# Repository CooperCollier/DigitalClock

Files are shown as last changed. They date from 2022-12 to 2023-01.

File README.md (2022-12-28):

# DigitalClock
A 12-hour digital clock made out of logic gates and flip-flops and implemented in Logisim.

This project incorporates the logisim 7-segment-display driver created here: https://github.com/marceloboeira/logisim-7-segment-display-driver.



How to open this project:

1: clone this repository with `git clone https://github.com/CooperCollier/DigitalClock --recursive`. The recursive tag is necessary to include the 7-segment-display driver.

2: Open the file clock.circ in logisim.

3: Under the 'simulate' tab, set 'tick frequency' to 2Hz.

4: Under the 'simulate' tab, set 'ticks enabled' to true.

How to use the clock:

Press the SET TIME button to make the clock enter or exit the SET TIME state. When the clock is in the SET TIME state, the SET TIME LED will be turned on. When the clock enters the SET TIME state, the time is immediately reset to 12:00 AM. 

Press the +MIN and +HOUR buttons to change the displayed time. These buttons are only active when the clock is in the SET TIME state.

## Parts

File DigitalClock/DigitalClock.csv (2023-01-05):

Collated Components:
Qty | Part name | Part type | Reference(s) | Value | LibPart | Footprint
1 | ~ |  | C1 | 10nF | Device:C_Small | Capacitor_THT:C_Disc_D5.0mm_W2.5mm_P5.00mm
3 | ~ |  | C2, C3, C4 | 100nF | Device:C_Small | Capacitor_THT:C_Disc_D5.0mm_W2.5mm_P5.00mm
3 | ~ |  | C5, C6, C7 | 10uF | Device:C_Small | Capacitor_THT:CP_Radial_Tantal_D5.0mm_P5.00mm
2 | LTL-4233 | LED | D1, D2 | LED | Device:LED | LED_THT:LED_D3.0mm
1 | ??? | Terminal Block | J1 | Battery | Connector:Conn_01x02_Female | TerminalBlock_Phoenix:TerminalBlock_Phoenix_MKDS-1,5-2_1x02_P5.00mm_Horizontal
3 | 2N3094 | BJT | Q1, Q2, Q3 | 2N3904 | Transistor_BJT:2N3904 | Package_TO_SOT_THT:TO-92_Inline
7 | ~ |  | R1, R2, R3, R4, R5, R6, R12 | 10k | Device:R_Small_US | Resistor_THT:R_Axial_DIN0207_L6.3mm_D2.5mm_P10.16mm_Horizontal
1 | ~ |  | R7 | 4.2k | Device:R_Small_US | Resistor_THT:R_Axial_DIN0207_L6.3mm_D2.5mm_P10.16mm_Horizontal
1 | ~ |  | R8 | 70 | Device:R_Small_US | Resistor_THT:R_Axial_DIN0207_L6.3mm_D2.5mm_P10.16mm_Horizontal
1 | ~ |  | R9 | 70k | Device:R_Small_US | Resistor_THT:R_Axial_DIN0207_L6.3mm_D2.5mm_P10.16mm_Horizontal
33 | ~ |  | R10, R11, R13, R14, R15, R16, R17, R18, R19, R20, R21, R22, R23, R24, R25, R26, R27, R28, R29, R30, R31, R32, R33, R34, R35, R36, R37, R38, R39, R40, R41, R42, R43 | 1k | Device:R_Small_US | Resistor_THT:R_Axial_DIN0207_L6.3mm_D2.5mm_P10.16mm_Horizontal
3 | B3F-1000 | B3F-1000 | SW1, SW2, SW3 | SW_Push | Switch:SW_Push | Button_Switch_THT:SW_PUSH_6mm
4 | SN74LS47N | BCD to 7 segment decoder | U1, U6, U8, U12 | 74LS47 | 74xx:74LS47 | Package_DIP:DIP-16_W7.62mm
1 | NE555P | 555 Timer | U2 | NE555P | Timer:NE555P | Package_DIP:DIP-8_W7.62mm
4 | LSHD-5601 | 7 segment display | U3, U7, U10, U14 | HDSP-7801 | Display_Character:HDSP-7801 | Display_7Segment:7SegmentLED_LTS6760_LTS6780
16 | SN74HC08N | AND gate | U4, U16, U20, U21, U25, U28, U29, U32, U33, U37, U42, U43, U47, U48, U51, U53 | 74LS08 | 74xx:74LS08 | Package_DIP:DIP-14_W7.62mm
4 | SN74HC32N | OR gate | U5, U49, U50, U52 | 74LS32 | 74xx:74LS32 | Package_DIP:DIP-14_W7.62mm
16 | SN74HC74N | Flip Flop | U9, U13, U17, U22, U23, U24, U26, U27, U31, U34, U35, U38, U40, U41, U45, U46 | 74LS74 | 74xx:74LS74 | Package_DIP:DIP-14_W7.62mm
1 | LM1117T-5.0/NOPB | Linear regulator (5V) | U11 | LM1117-5.0 | Regulator_Linear:LM1117-5.0 | Package_TO_SOT_THT:TO-220-3_Vertical
2 | SN74LS14N | Inverter (schmitt triggered) | U15, U54 | 74LS04 | 74xx:74LS04 | Package_DIP:DIP-14_W7.62mm
6 | SN74HC86N | XOR gate | U18, U19, U30, U36, U39, U44 | 74LS86 | 74xx:74LS86 | Package_DIP:DIP-14_W7.62mm

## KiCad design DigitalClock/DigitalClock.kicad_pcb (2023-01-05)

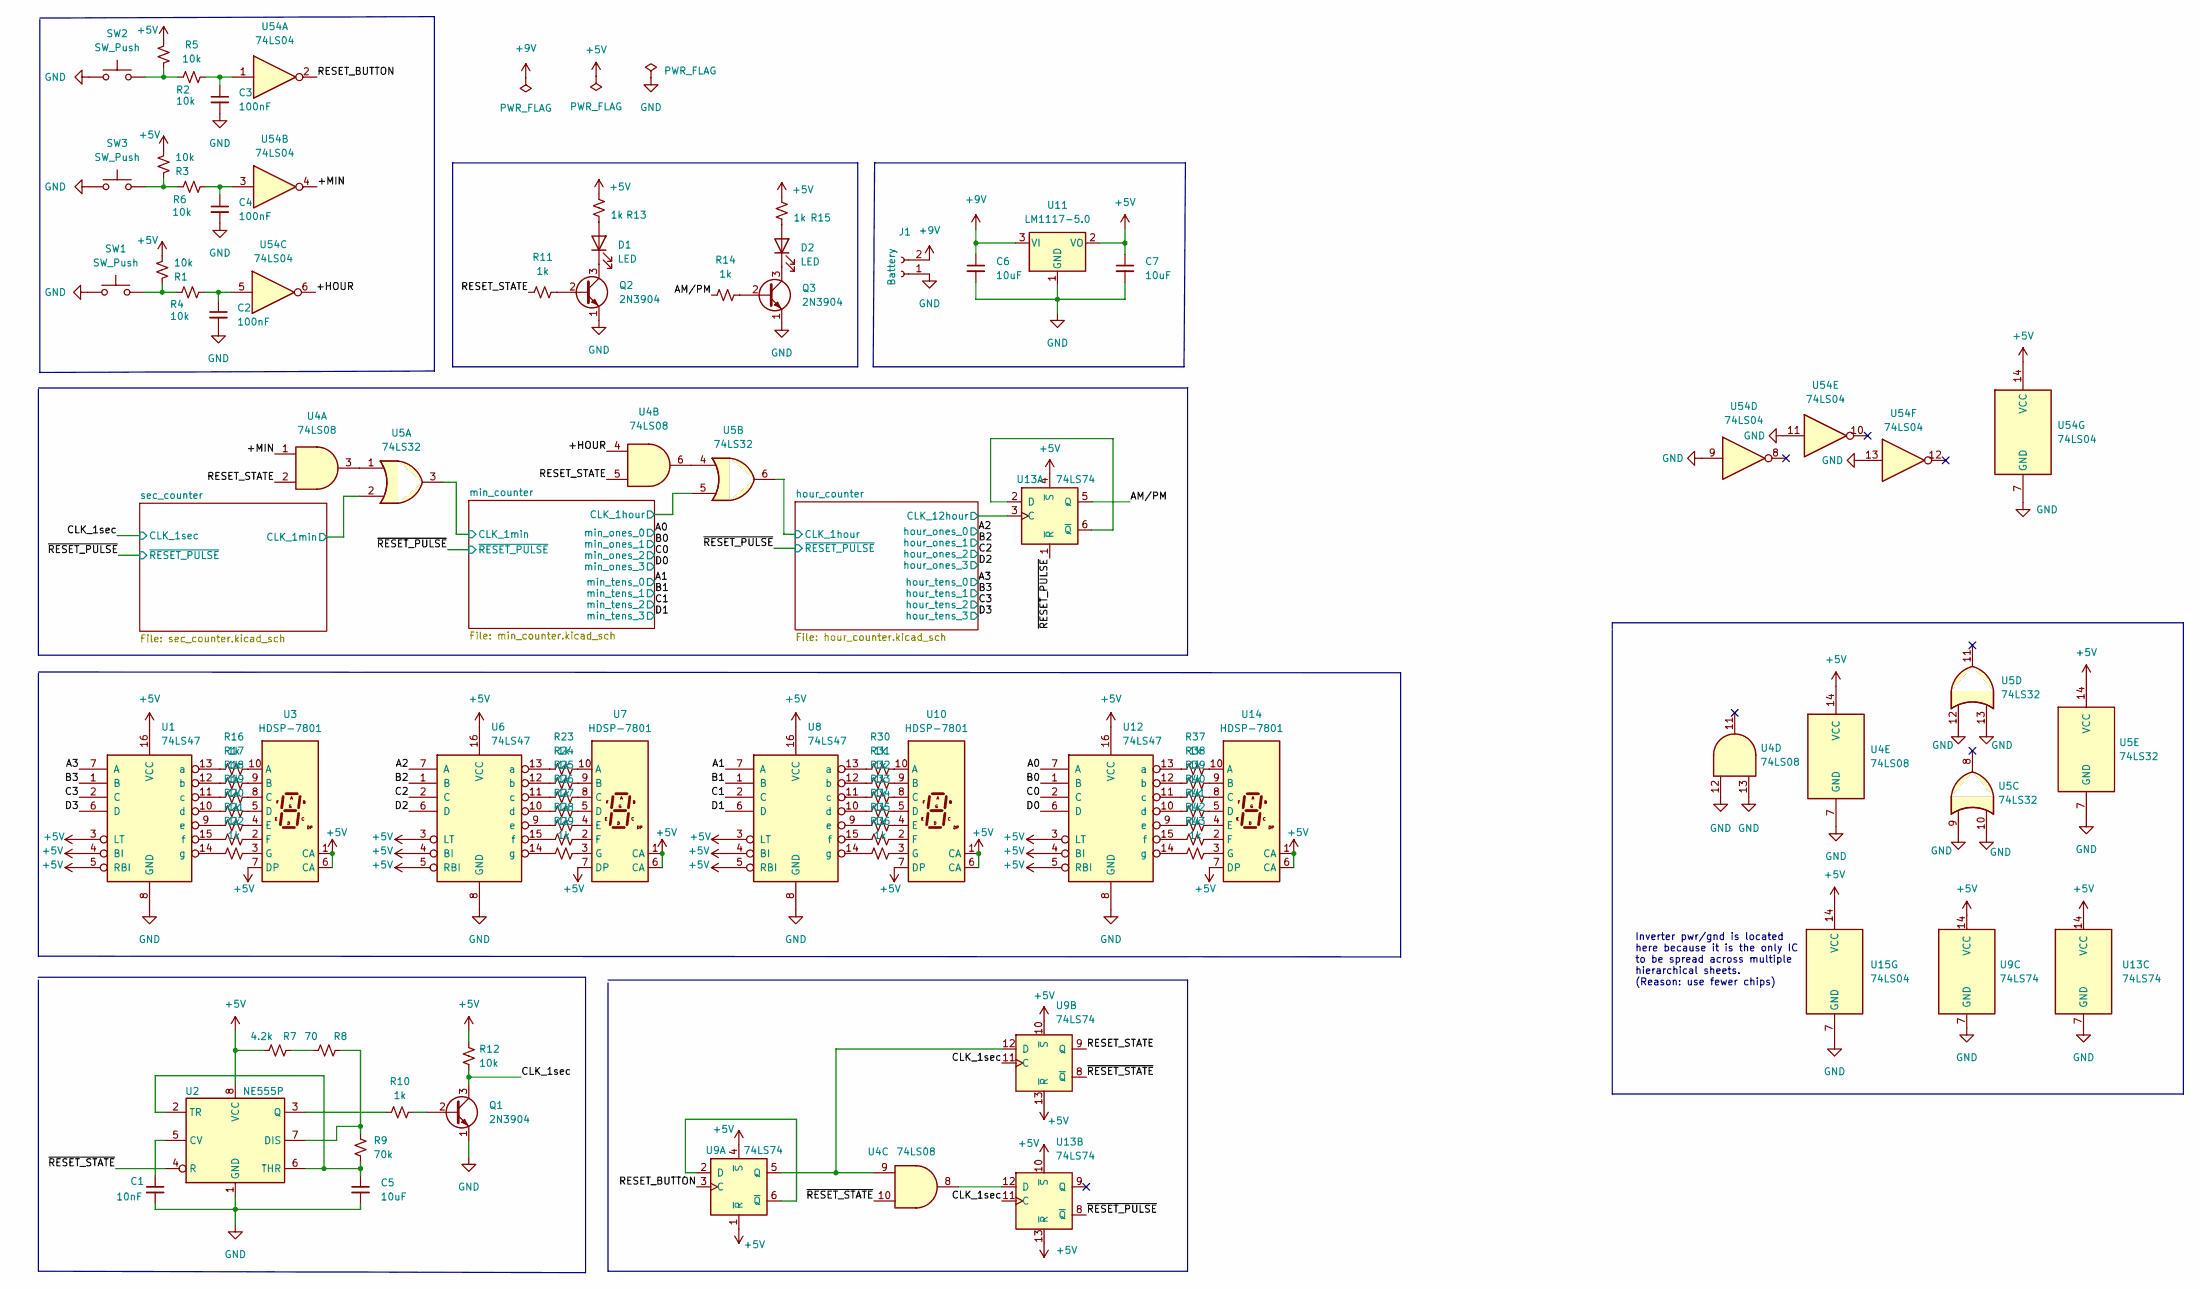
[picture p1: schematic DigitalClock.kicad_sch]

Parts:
C1: 10nF; C_Disc_D5.0mm_W2.5mm_P5.00mm
C2, C3, C4: 100nF; C_Disc_D5.0mm_W2.5mm_P5.00mm
C5, C6, C7: 10uF; CP_Radial_Tantal_D5.0mm_P5.00mm
D1, D2: LED; LED_D3.0mm
J1: Battery; TerminalBlock_Phoenix_MKDS-1,5-2_1x02_P5.00mm_Horizontal
Q1, Q2, Q3: 2N3904; TO-92_Inline
R1, R2, R3, R4, R5, R6, R12: 10k; R_Axial_DIN0207_L6.3mm_D2.5mm_P10.16mm_Horizontal
R7: 4.2k; R_Axial_DIN0207_L6.3mm_D2.5mm_P10.16mm_Horizontal
R8: 70; R_Axial_DIN0207_L6.3mm_D2.5mm_P10.16mm_Horizontal
R9: 70k; R_Axial_DIN0207_L6.3mm_D2.5mm_P10.16mm_Horizontal
R10, R11, R13, R14, R15, R16, R17, R18, R19, R20, R21, R22, R23, R24, R25, R26, R27, R28, R29, R30, R31, R32, R33, R34, R35, R36, R37, R38, R39, R40, R41, R42, R43: 1k; R_Axial_DIN0207_L6.3mm_D2.5mm_P10.16mm_Horizontal
SW1, SW2, SW3: SW_Push; SW_PUSH_6mm
U1, U6, U8, U12: 74LS47; DIP-16_W7.62mm
U2: NE555P; DIP-8_W7.62mm
U3, U7, U10, U14: HDSP-7801; 7SegmentLED_LTS6760_LTS6780
U4: 74LS08; DIP-14_W7.62mm
U5: 74LS32; DIP-14_W7.62mm
U9, U13: 74LS74; DIP-14_W7.62mm
U11: LM1117-5.0; TO-220-3_Vertical
U15, U54: 74LS04; DIP-14_W7.62mm

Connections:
+5V: C7.1, R1.2, R2.2, R3.2, R7.1, R12.2, R13.2, R15.2, U1.3 (LT), U1.4 (BI), U1.5 (RBI), U1.16 (VCC), U2.8 (VCC), U3.1 (CA), U3.6 (CA), U3.7 (DP), U4.14 (VCC), U5.14 (VCC), U6.3 (LT), U6.4 (BI), U6.5 (RBI), U6.16 (VCC), U7.1 (CA), U7.6 (CA), U7.7 (DP), U8.3 (LT), U8.4 (BI), U8.5 (RBI), U8.16 (VCC), U9.1 (~R), U9.4 (~S), U9.10 (~S), U9.13 (~R), U9.14 (VCC), U10.1 (CA), U10.6 (CA), U10.7 (DP), U11.2 (VO), U12.3 (LT), U12.4 (BI), U12.5 (RBI), U12.16 (VCC), U13.4 (~S), U13.10 (~S), U13.13 (~R), U13.14 (VCC), U14.1 (CA), U14.6 (CA), U14.7 (DP), U15.14 (VCC), U54.14 (VCC); also elsewhere on the board
+9V: C6.1, J1.2, U11.3 (VI)
/+HOUR: U4.4, U54.6
/+MIN: U4.1, U54.4
/A0: U12.7 (A); also elsewhere on the board
/A1: U8.7 (A); also elsewhere on the board
/A2: U6.7 (A); also elsewhere on the board
/A3: U1.7 (A); also elsewhere on the board
/AM/PM: R14.1, U13.5 (Q)
/B0: U12.1 (B); also elsewhere on the board
/B1: U8.1 (B); also elsewhere on the board
/B2: U6.1 (B); also elsewhere on the board
/B3: U1.1 (B); also elsewhere on the board
/C0: U12.2 (C); also elsewhere on the board
/C1: U8.2 (C); also elsewhere on the board
/C2: U6.2 (C); also elsewhere on the board
/C3: U1.2 (C); also elsewhere on the board
/CLK_1sec: Q1.3 (C), R12.1, U9.11 (C), U13.11 (C); also elsewhere on the board
/D0: U12.6 (D); also elsewhere on the board
/D1: U8.6 (D); also elsewhere on the board
/D2: U6.6 (D); also elsewhere on the board
/D3: U1.6 (D); also elsewhere on the board
/RESET_BUTTON: U9.3 (C), U54.2
/RESET_STATE: R11.1, U4.2, U4.5, U9.9 (Q)
/hour_counter/CLK_1hour: U5.6; also elsewhere on the board
/hour_counter/CLK_12hour: U13.3 (C); also elsewhere on the board
/min_counter/CLK_1hour: U5.5; also elsewhere on the board
/min_counter/CLK_1min: U5.3; also elsewhere on the board
/sec_counter/CLK_1min: U5.2; also elsewhere on the board
/~RESET_PULSE: U13.1 (~R), U13.8 (~Q); also elsewhere on the board
/~RESET_STATE: U2.4 (R), U4.10, U9.8 (~Q)
GND: C1.2, C2.2, C3.2, C4.2, C5.2, C6.2, C7.2, J1.1, Q1.1 (E), Q2.1 (E), Q3.1 (E), SW1.1, SW2.1, SW3.1, U1.8 (GND), U2.1 (GND), U4.7 (GND), U4.12, U4.13, U5.7 (GND), U5.9, U5.10, U5.12, U5.13, U6.8 (GND), U8.8 (GND), U9.7 (GND), U11.1 (GND), U12.8 (GND), U13.7 (GND), U15.7 (GND), U54.7 (GND), U54.9, U54.11, U54.13; also elsewhere on the board
unnamed: C1.1, U2.5 (CV)
unnamed: C2.1, R4.2, U54.5
unnamed: C3.1, R5.2, U54.1
unnamed: C4.1, R6.2, U54.3
unnamed: C5.1, R9.2, U2.2 (TR), U2.6 (THR)
unnamed: D1.1 (K), Q2.3 (C)
unnamed: D1.2 (A), R13.1
unnamed: D2.1 (K), Q3.3 (C)
unnamed: D2.2 (A), R15.1
unnamed: Q1.2 (B), R10.2
unnamed: Q2.2 (B), R11.2
unnamed: Q3.2 (B), R14.2
unnamed: R1.1, R4.1, SW1.2
unnamed: R2.1, R5.1, SW2.2
unnamed: R3.1, R6.1, SW3.2
unnamed: R7.2, R8.1
unnamed: R8.2, R9.1, U2.7 (DIS)
unnamed: R10.1, U2.3 (Q)
unnamed: R16.1, U1.13 (a)
unnamed: R16.2, U3.10 (A)
unnamed: R17.1, U1.12 (b)
unnamed: R17.2, U3.9 (B)
unnamed: R18.1, U1.11 (c)
unnamed: R18.2, U3.8 (C)
unnamed: R19.1, U1.10 (d)
unnamed: R19.2, U3.5 (D)
unnamed: R20.1, U1.9 (e)
unnamed: R20.2, U3.4 (E)
unnamed: R21.1, U1.15 (f)
unnamed: R21.2, U3.2 (F)
unnamed: R22.1, U1.14 (g)
unnamed: R22.2, U3.3 (G)
unnamed: R23.1, U6.13 (a)
unnamed: R23.2, U7.10 (A)
unnamed: R24.1, U6.12 (b)
unnamed: R24.2, U7.9 (B)
unnamed: R25.1, U6.11 (c)
unnamed: R25.2, U7.8 (C)
unnamed: R26.1, U6.10 (d)
unnamed: R26.2, U7.5 (D)
unnamed: R27.1, U6.9 (e)
unnamed: R27.2, U7.4 (E)
unnamed: R28.1, U6.15 (f)
unnamed: R28.2, U7.2 (F)
unnamed: R29.1, U6.14 (g)
unnamed: R29.2, U7.3 (G)
unnamed: R30.1, U8.13 (a)
unnamed: R30.2, U10.10 (A)
unnamed: R31.1, U8.12 (b)
unnamed: R31.2, U10.9 (B)
unnamed: R32.1, U8.11 (c)
unnamed: R32.2, U10.8 (C)
unnamed: R33.1, U8.10 (d)
unnamed: R33.2, U10.5 (D)
unnamed: R34.1, U8.9 (e)
unnamed: R34.2, U10.4 (E)
unnamed: R35.1, U8.15 (f)
unnamed: R35.2, U10.2 (F)
unnamed: R36.1, U8.14 (g)
unnamed: R36.2, U10.3 (G)
unnamed: R37.1, U12.13 (a)
unnamed: R37.2, U14.10 (A)
unnamed: R38.1, U12.12 (b)
unnamed: R38.2, U14.9 (B)
unnamed: R39.1, U12.11 (c)
unnamed: R39.2, U14.8 (C)
unnamed: R40.1, U12.10 (d)
unnamed: R40.2, U14.5 (D)
unnamed: R41.1, U12.9 (e)
unnamed: R41.2, U14.4 (E)
unnamed: R42.1, U12.15 (f)
unnamed: R42.2, U14.2 (F)
unnamed: R43.1, U12.14 (g)
unnamed: R43.2, U14.3 (G)
unnamed: U4.3, U5.1
unnamed: U4.6, U5.4
unnamed: U4.9, U9.5 (Q), U9.12 (D)
unnamed: U9.2 (D), U9.6 (~Q)
unnamed: U13.2 (D), U13.6 (~Q)
unnamed: U4.8, U13.12 (D)

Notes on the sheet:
Inverter pwr/gnd is located here because it is the only IC to be spread across multiple hierarchical sheets. (Reason: use fewer chips)

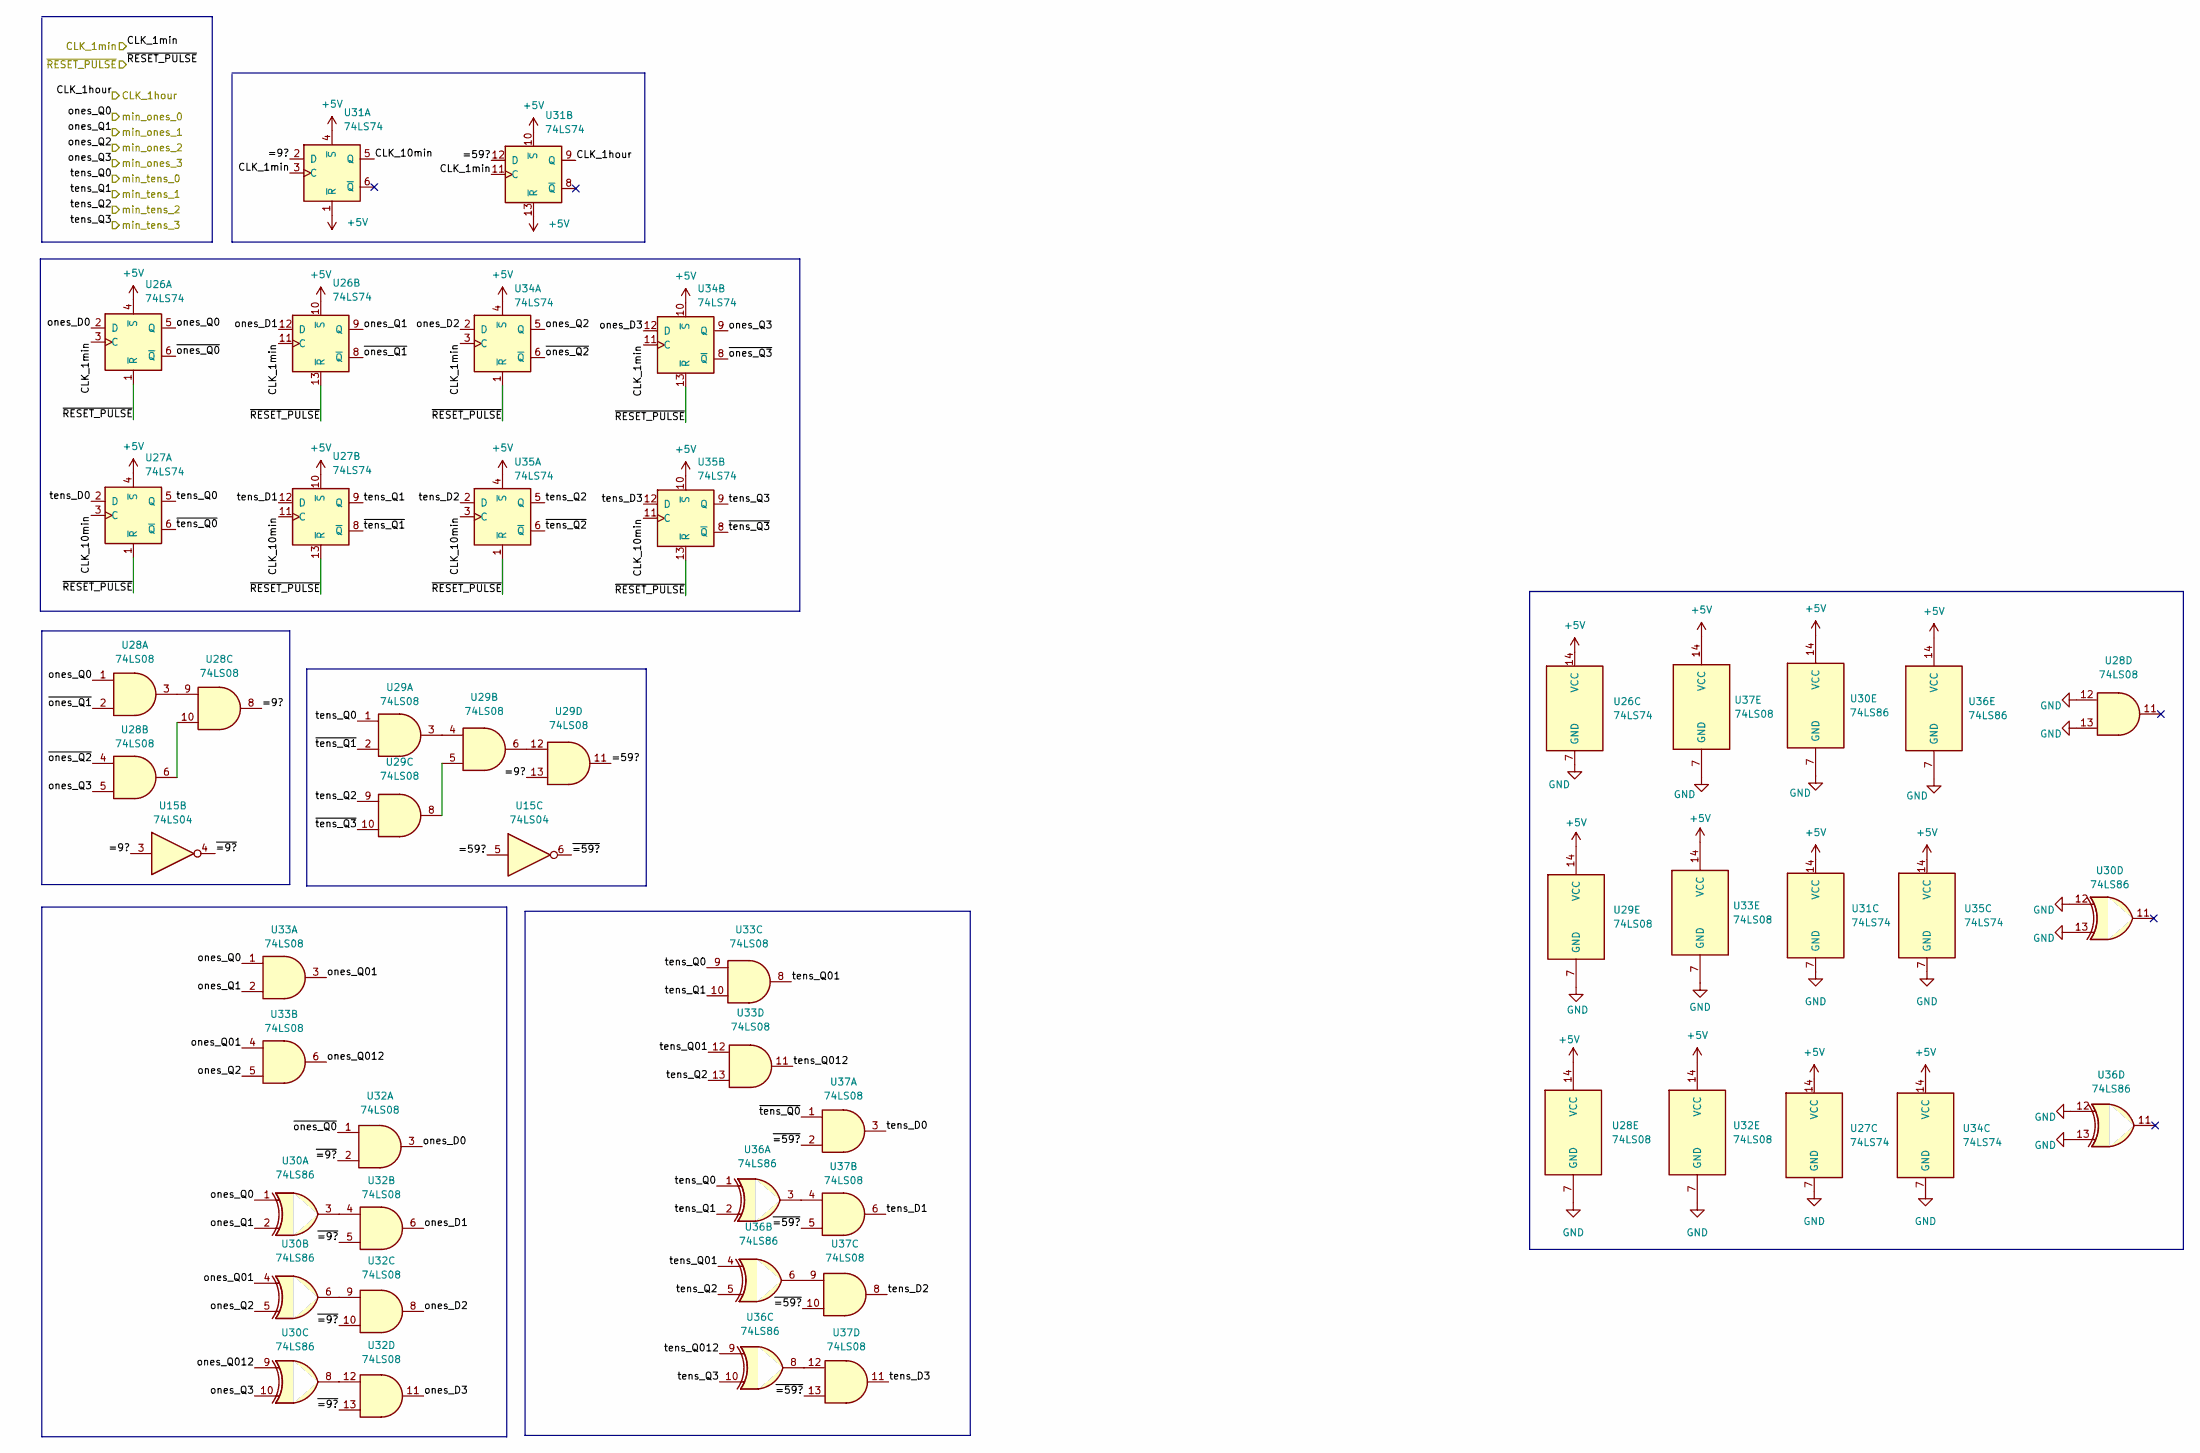
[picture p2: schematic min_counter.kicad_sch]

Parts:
U15: 74LS04; DIP-14_W7.62mm
U26, U27, U31, U34, U35: 74LS74; DIP-14_W7.62mm
U28, U29, U32, U33, U37: 74LS08; DIP-14_W7.62mm
U30, U36: 74LS86; DIP-14_W7.62mm

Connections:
+5V: U26.4 (~S), U26.10 (~S), U26.14 (VCC), U27.4 (~S), U27.10 (~S), U27.14 (VCC), U28.14 (VCC), U29.14 (VCC), U30.14 (VCC), U31.1 (~R), U31.4 (~S), U31.10 (~S), U31.13 (~R), U31.14 (VCC), U32.14 (VCC), U33.14 (VCC), U34.4 (~S), U34.10 (~S), U34.14 (VCC), U35.4 (~S), U35.10 (~S), U35.14 (VCC), U36.14 (VCC), U37.14 (VCC); also elsewhere on the board
/A0: U26.5 (Q), U28.1, U30.1, U33.1; also elsewhere on the board
/A1: U27.5 (Q), U29.1, U33.9, U36.1; also elsewhere on the board
/B0: U26.9 (Q), U30.2, U33.2; also elsewhere on the board
/B1: U27.9 (Q), U33.10, U36.2; also elsewhere on the board
/C0: U30.5, U33.5, U34.5 (Q); also elsewhere on the board
/C1: U29.9, U33.13, U35.5 (Q), U36.5; also elsewhere on the board
/D0: U28.5, U30.10, U34.9 (Q); also elsewhere on the board
/D1: U35.9 (Q), U36.10; also elsewhere on the board
/min_counter/=9?: U15.3, U28.8, U29.13, U31.2 (D)
/min_counter/=59?: U15.5, U29.11, U31.12 (D)
/min_counter/CLK_1hour: U31.9 (Q); also elsewhere on the board
/min_counter/CLK_1min: U26.3 (C), U26.11 (C), U31.3 (C), U31.11 (C), U34.3 (C), U34.11 (C); also elsewhere on the board
/min_counter/CLK_10min: U27.3 (C), U27.11 (C), U31.5 (Q), U35.3 (C), U35.11 (C)
/min_counter/ones_D0: U26.2 (D), U32.3
/min_counter/ones_D1: U26.12 (D), U32.6
/min_counter/ones_D2: U32.8, U34.2 (D)
/min_counter/ones_D3: U32.11, U34.12 (D)
/min_counter/ones_Q01: U30.4, U33.3, U33.4
/min_counter/ones_Q012: U30.9, U33.6
/min_counter/tens_D0: U27.2 (D), U37.3
/min_counter/tens_D1: U27.12 (D), U37.6
/min_counter/tens_D2: U35.2 (D), U37.8
/min_counter/tens_D3: U35.12 (D), U37.11
/min_counter/tens_Q01: U33.8, U33.12, U36.4
/min_counter/tens_Q012: U33.11, U36.9
/min_counter/~=9?: U15.4, U32.2, U32.5, U32.10, U32.13
/min_counter/~=59?: U15.6, U37.2, U37.5, U37.10, U37.13
/min_counter/~ones_Q0: U26.6 (~Q), U32.1
/min_counter/~ones_Q1: U26.8 (~Q), U28.2
/min_counter/~ones_Q2: U28.4, U34.6 (~Q)
/min_counter/~ones_Q3: U34.8 (~Q)
/min_counter/~tens_Q0: U27.6 (~Q), U37.1
/min_counter/~tens_Q1: U27.8 (~Q), U29.2
/min_counter/~tens_Q2: U35.6 (~Q)
/min_counter/~tens_Q3: U29.10, U35.8 (~Q)
/~RESET_PULSE: U26.1 (~R), U26.13 (~R), U27.1 (~R), U27.13 (~R), U34.1 (~R), U34.13 (~R), U35.1 (~R), U35.13 (~R); also elsewhere on the board
GND: U26.7 (GND), U27.7 (GND), U28.7 (GND), U28.12, U28.13, U29.7 (GND), U30.7 (GND), U30.12, U30.13, U31.7 (GND), U32.7 (GND), U33.7 (GND), U34.7 (GND), U35.7 (GND), U36.7 (GND), U36.12, U36.13, U37.7 (GND); also elsewhere on the board
unnamed: U28.3, U28.9
unnamed: U28.6, U28.10
unnamed: U29.3, U29.4
unnamed: U29.5, U29.8
unnamed: U29.6, U29.12
unnamed: U30.3, U32.4
unnamed: U30.6, U32.9
unnamed: U30.8, U32.12
unnamed: U36.3, U37.4
unnamed: U36.6, U37.9
unnamed: U36.8, U37.12

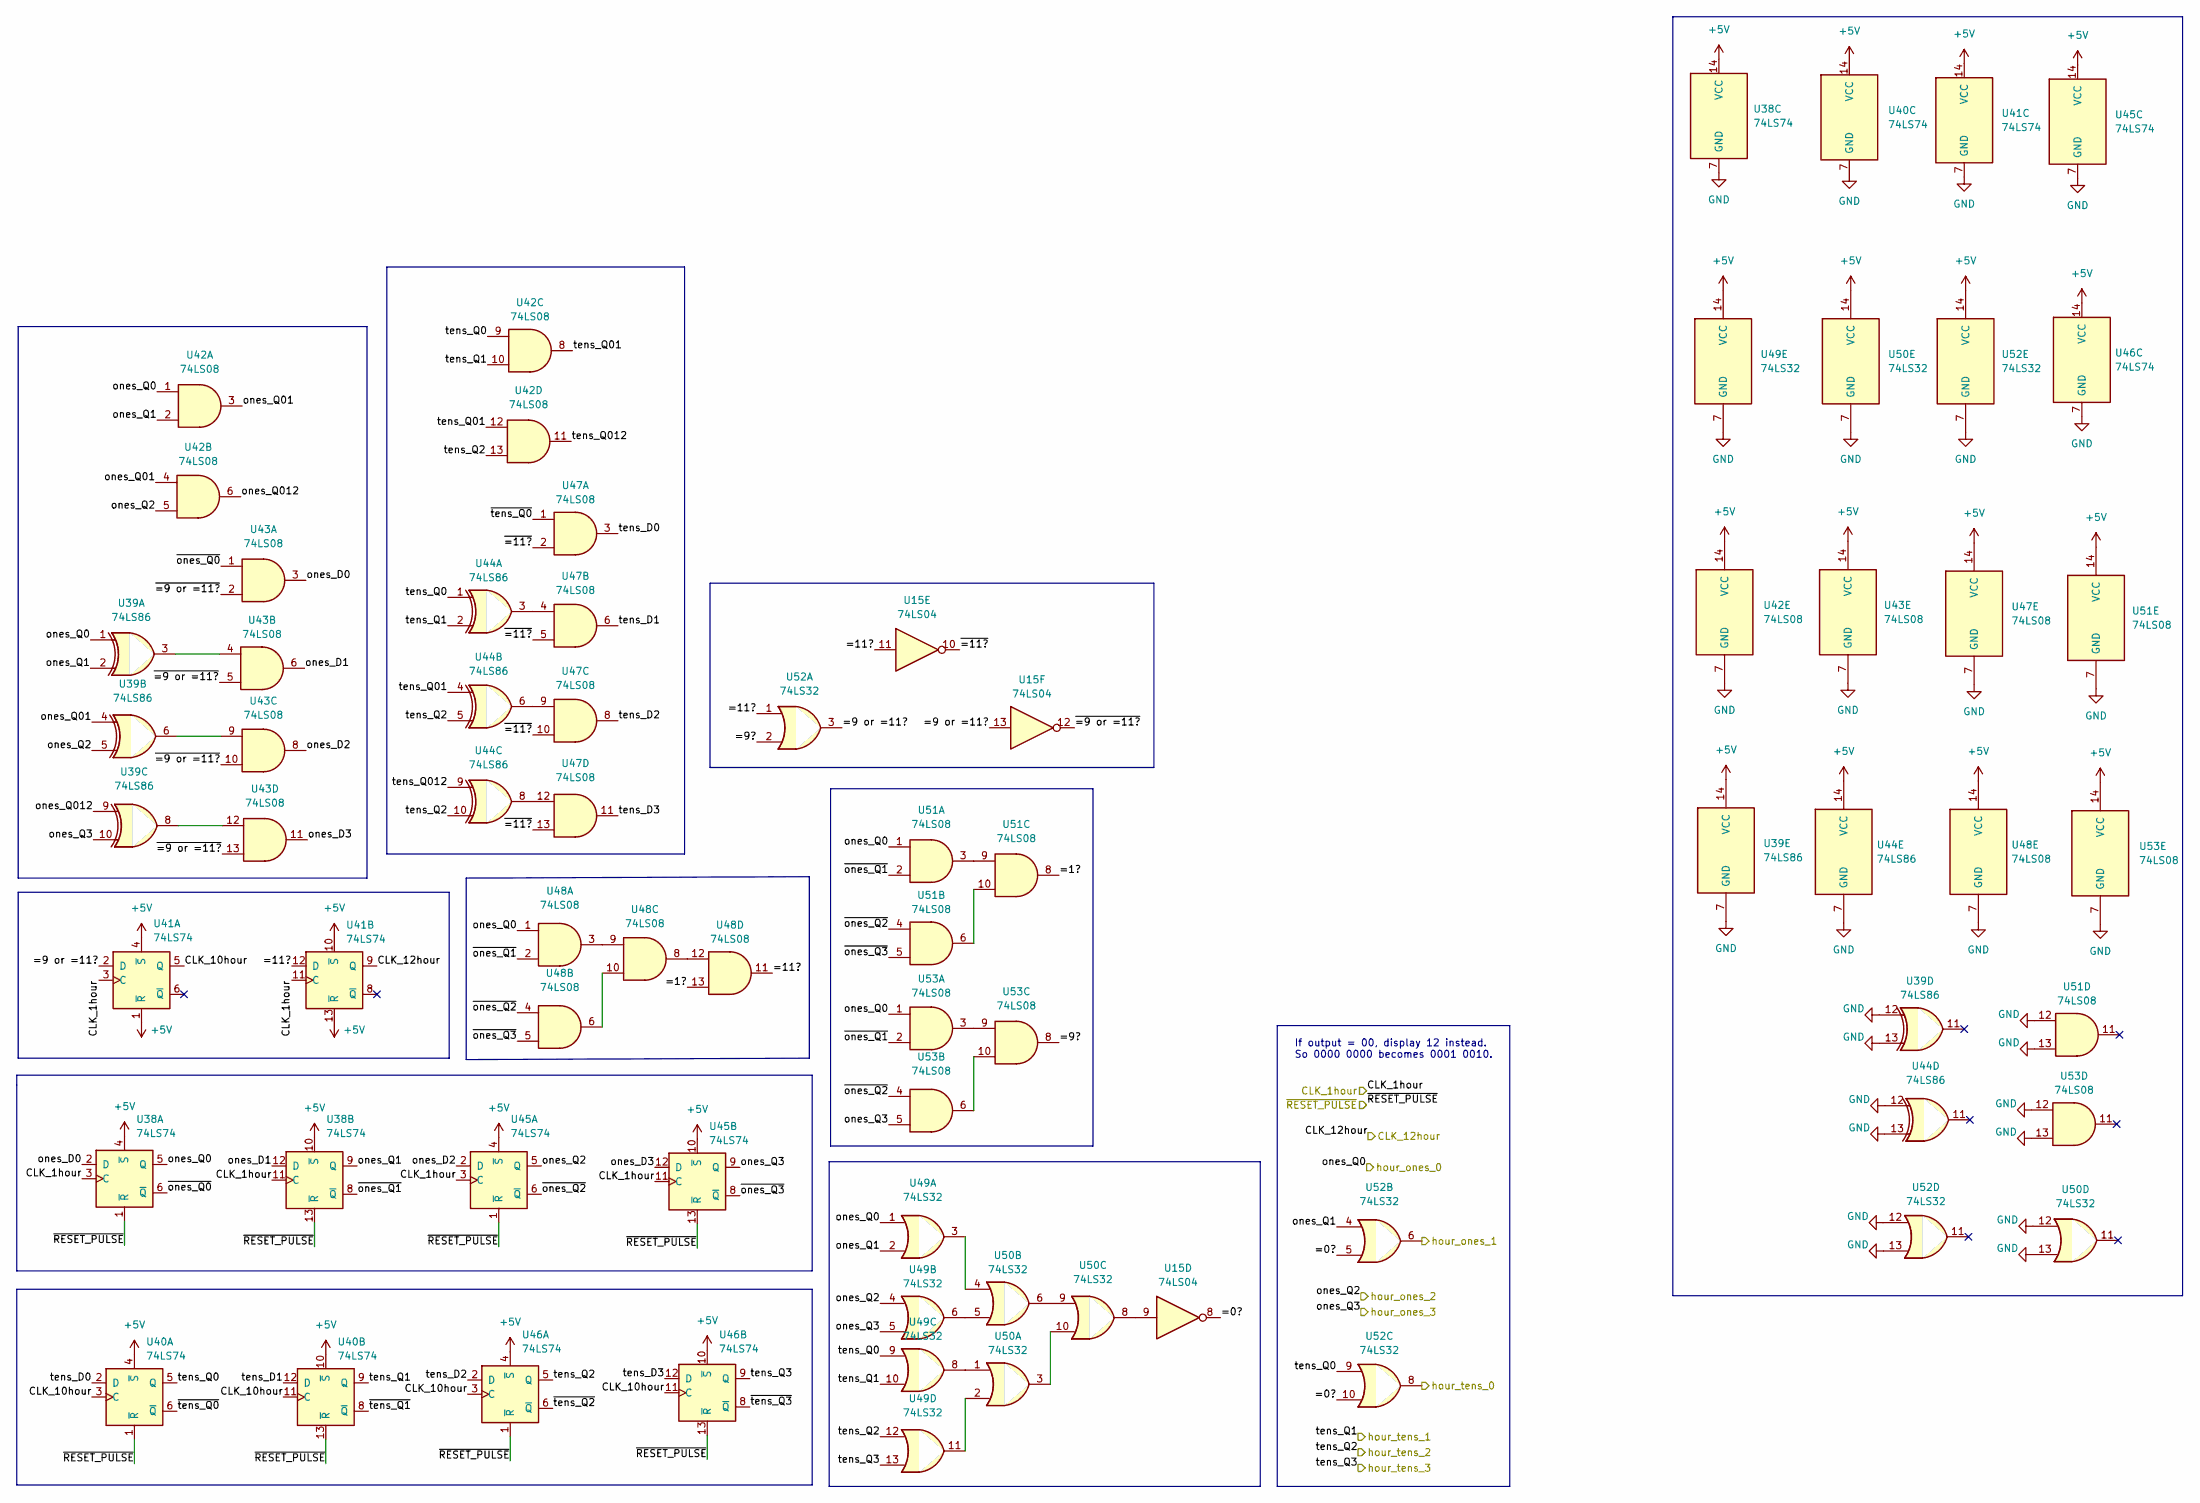
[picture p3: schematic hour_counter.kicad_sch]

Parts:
U15: 74LS04; DIP-14_W7.62mm
U38, U40, U41, U45, U46: 74LS74; DIP-14_W7.62mm
U39, U44: 74LS86; DIP-14_W7.62mm
U42, U43, U47, U48, U51, U53: 74LS08; DIP-14_W7.62mm
U49, U50, U52: 74LS32; DIP-14_W7.62mm

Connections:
+5V: U38.4 (~S), U38.10 (~S), U38.14 (VCC), U39.14 (VCC), U40.4 (~S), U40.10 (~S), U40.14 (VCC), U41.1 (~R), U41.4 (~S), U41.10 (~S), U41.13 (~R), U41.14 (VCC), U42.14 (VCC), U43.14 (VCC), U44.14 (VCC), U45.4 (~S), U45.10 (~S), U45.14 (VCC), U46.4 (~S), U46.10 (~S), U46.14 (VCC), U47.14 (VCC), U48.14 (VCC), U49.14 (VCC), U50.14 (VCC), U51.14 (VCC), U52.14 (VCC), U53.14 (VCC); also elsewhere on the board
/A2: U38.5 (Q), U39.1, U42.1, U48.1, U49.1, U51.1, U53.1; also elsewhere on the board
/A3: U52.8; also elsewhere on the board
/B2: U52.6; also elsewhere on the board
/B3: U40.9 (Q), U42.10, U44.2, U49.10; also elsewhere on the board
/C2: U39.5, U42.5, U45.5 (Q), U49.4; also elsewhere on the board
/C3: U42.13, U44.5, U44.10, U46.5 (Q), U49.12; also elsewhere on the board
/D2: U39.10, U45.9 (Q), U49.5, U53.5; also elsewhere on the board
/D3: U46.9 (Q), U49.13; also elsewhere on the board
/hour_counter/=0?: U15.8, U52.5, U52.10
/hour_counter/=1?: U48.13, U51.8
/hour_counter/=9 or =11?: U15.13, U41.2 (D), U52.3
/hour_counter/=9?: U52.2, U53.8
/hour_counter/=11?: U15.11, U41.12 (D), U48.11, U52.1
/hour_counter/CLK_1hour: U38.3 (C), U38.11 (C), U41.3 (C), U41.11 (C), U45.3 (C), U45.11 (C); also elsewhere on the board
/hour_counter/CLK_10hour: U40.3 (C), U40.11 (C), U41.5 (Q), U46.3 (C), U46.11 (C)
/hour_counter/CLK_12hour: U41.9 (Q); also elsewhere on the board
/hour_counter/ones_D0: U38.2 (D), U43.3
/hour_counter/ones_D1: U38.12 (D), U43.6
/hour_counter/ones_D2: U43.8, U45.2 (D)
/hour_counter/ones_D3: U43.11, U45.12 (D)
/hour_counter/ones_Q1: U38.9 (Q), U39.2, U42.2, U49.2, U52.4
/hour_counter/ones_Q01: U39.4, U42.3, U42.4
/hour_counter/ones_Q012: U39.9, U42.6
/hour_counter/tens_D0: U40.2 (D), U47.3
/hour_counter/tens_D1: U40.12 (D), U47.6
/hour_counter/tens_D2: U46.2 (D), U47.8
/hour_counter/tens_D3: U46.12 (D), U47.11
/hour_counter/tens_Q0: U40.5 (Q), U42.9, U44.1, U49.9, U52.9
/hour_counter/tens_Q01: U42.8, U42.12, U44.4
/hour_counter/tens_Q012: U42.11, U44.9
/hour_counter/~=9 or =11?: U15.12, U43.2, U43.5, U43.10, U43.13
/hour_counter/~=11?: U15.10, U47.2, U47.5, U47.10, U47.13
/hour_counter/~ones_Q0: U38.6 (~Q), U43.1
/hour_counter/~ones_Q1: U38.8 (~Q), U48.2, U51.2, U53.2
/hour_counter/~ones_Q2: U45.6 (~Q), U48.4, U51.4, U53.4
/hour_counter/~ones_Q3: U45.8 (~Q), U48.5, U51.5
/hour_counter/~tens_Q0: U40.6 (~Q), U47.1
/hour_counter/~tens_Q1: U40.8 (~Q)
/hour_counter/~tens_Q2: U46.6 (~Q)
/hour_counter/~tens_Q3: U46.8 (~Q)
/~RESET_PULSE: U38.1 (~R), U38.13 (~R), U40.1 (~R), U40.13 (~R), U45.1 (~R), U45.13 (~R), U46.1 (~R), U46.13 (~R); also elsewhere on the board
GND: U38.7 (GND), U39.7 (GND), U39.12, U39.13, U40.7 (GND), U41.7 (GND), U42.7 (GND), U43.7 (GND), U44.7 (GND), U44.12, U44.13, U45.7 (GND), U46.7 (GND), U47.7 (GND), U48.7 (GND), U49.7 (GND), U50.7 (GND), U50.12, U50.13, U51.7 (GND), U51.12, U51.13, U52.7 (GND), U52.12, U52.13, U53.7 (GND), U53.12, U53.13; also elsewhere on the board
unnamed: U15.9, U50.8
unnamed: U39.3, U43.4
unnamed: U39.6, U43.9
unnamed: U39.8, U43.12
unnamed: U44.3, U47.4
unnamed: U44.6, U47.9
unnamed: U44.8, U47.12
unnamed: U48.3, U48.9
unnamed: U48.6, U48.10
unnamed: U48.8, U48.12
unnamed: U49.3, U50.4
unnamed: U49.6, U50.5
unnamed: U49.8, U50.1
unnamed: U49.11, U50.2
unnamed: U50.6, U50.9
unnamed: U50.3, U50.10
unnamed: U51.3, U51.9
unnamed: U51.6, U51.10
unnamed: U53.3, U53.9
unnamed: U53.6, U53.10

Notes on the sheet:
If output = 00, display 12 instead. So 0000 0000 becomes 0001 0010.

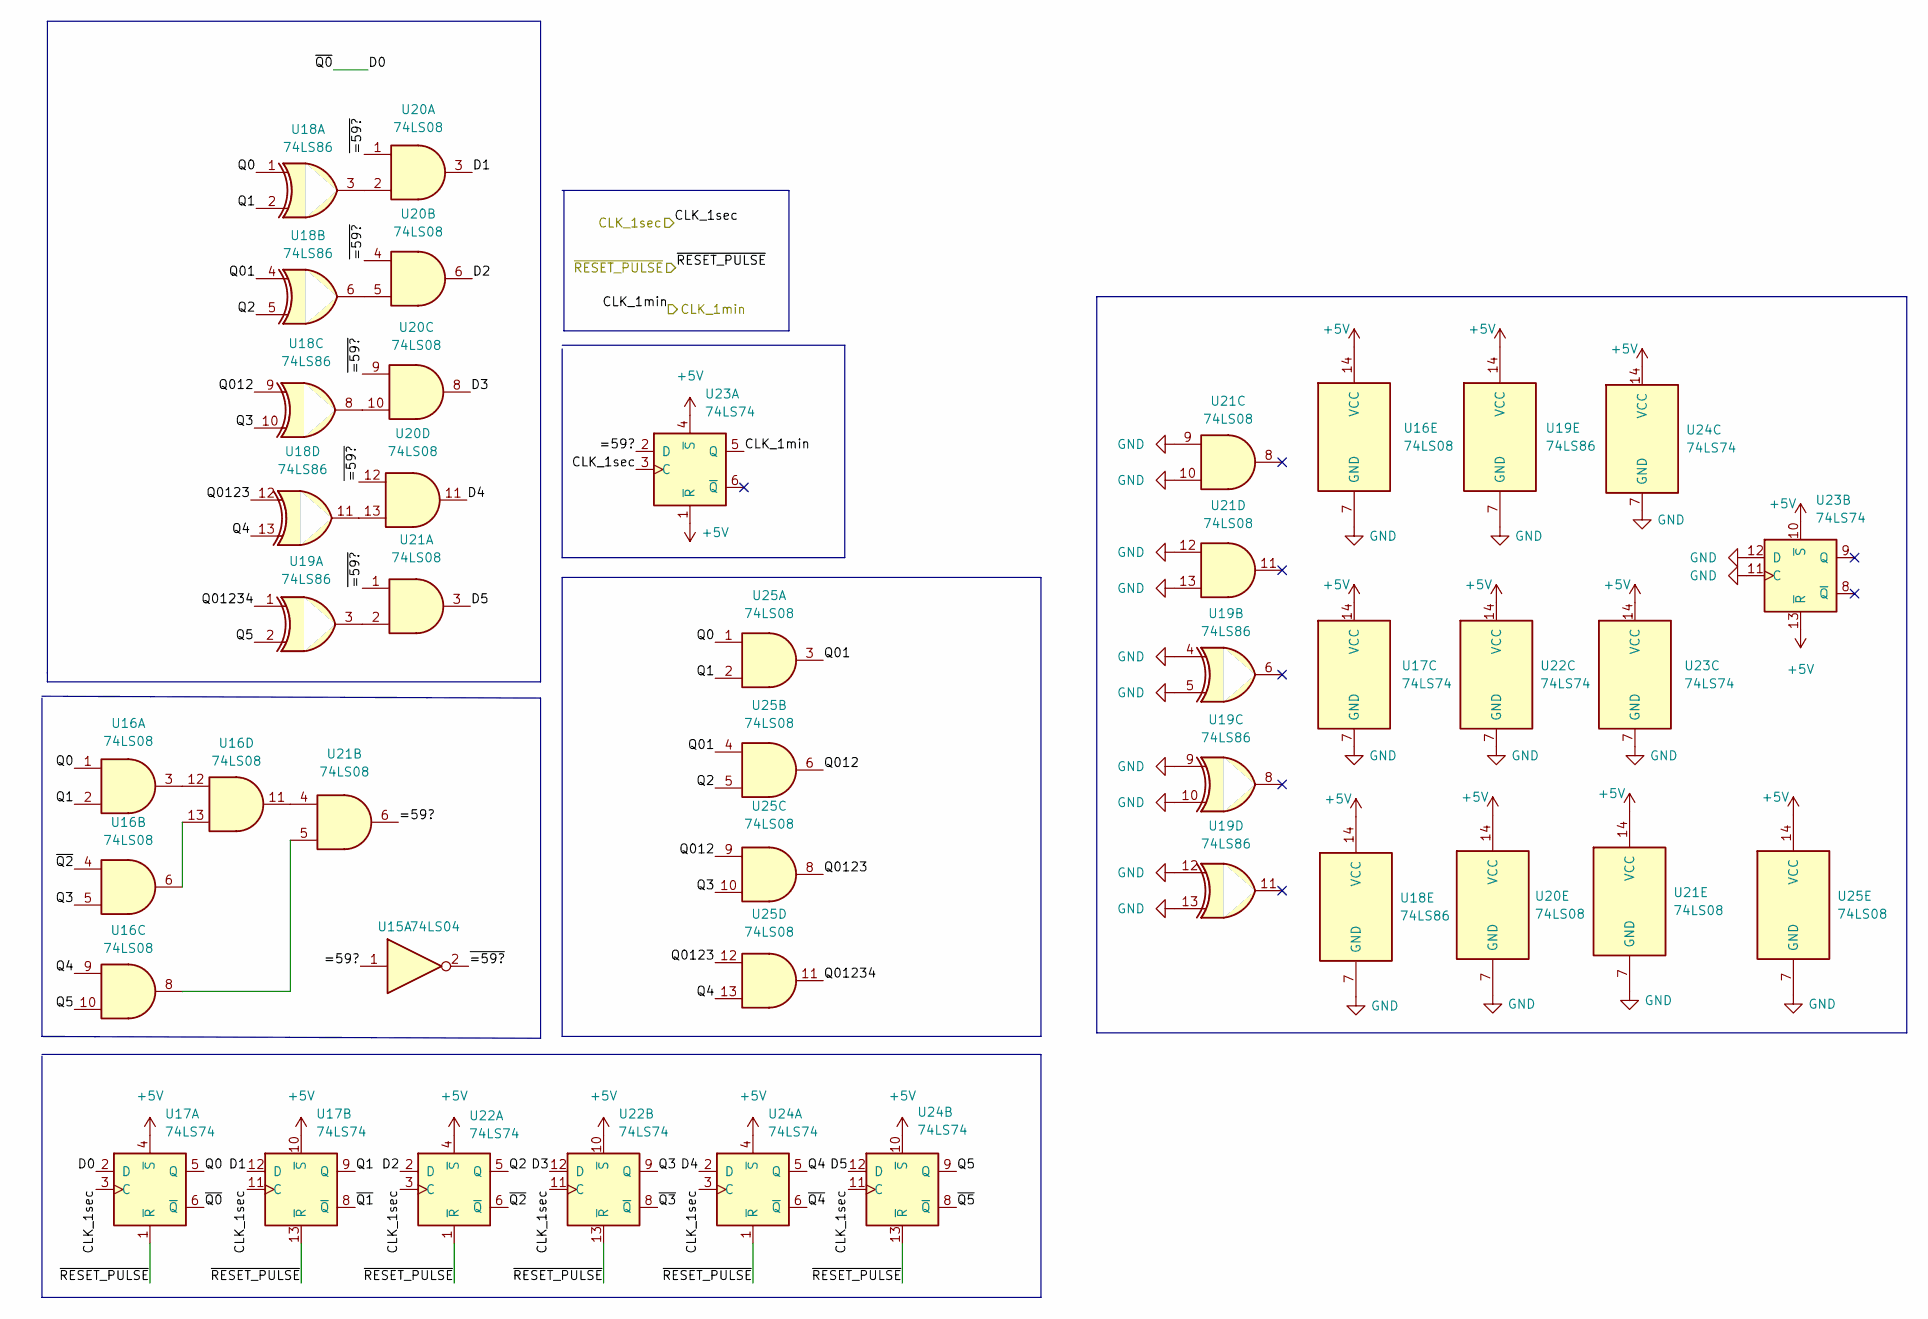
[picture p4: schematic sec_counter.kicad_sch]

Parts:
U15: 74LS04; DIP-14_W7.62mm
U16, U20, U21, U25: 74LS08; DIP-14_W7.62mm
U17, U22, U23, U24: 74LS74; DIP-14_W7.62mm
U18, U19: 74LS86; DIP-14_W7.62mm

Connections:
+5V: U16.14 (VCC), U17.4 (~S), U17.10 (~S), U17.14 (VCC), U18.14 (VCC), U19.14 (VCC), U20.14 (VCC), U21.14 (VCC), U22.4 (~S), U22.10 (~S), U22.14 (VCC), U23.1 (~R), U23.4 (~S), U23.10 (~S), U23.13 (~R), U23.14 (VCC), U24.4 (~S), U24.10 (~S), U24.14 (VCC), U25.14 (VCC); also elsewhere on the board
/CLK_1sec: U17.3 (C), U17.11 (C), U22.3 (C), U22.11 (C), U23.3 (C), U24.3 (C), U24.11 (C); also elsewhere on the board
/sec_counter/=59?: U15.1, U21.6, U23.2 (D)
/sec_counter/CLK_1min: U23.5 (Q); also elsewhere on the board
/sec_counter/D0: U17.2 (D), U17.6 (~Q)
/sec_counter/D1: U17.12 (D), U20.3
/sec_counter/D2: U20.6, U22.2 (D)
/sec_counter/D3: U20.8, U22.12 (D)
/sec_counter/D4: U20.11, U24.2 (D)
/sec_counter/D5: U21.3, U24.12 (D)
/sec_counter/Q0: U16.1, U17.5 (Q), U18.1, U25.1
/sec_counter/Q1: U16.2, U17.9 (Q), U18.2, U25.2
/sec_counter/Q01: U18.4, U25.3, U25.4
/sec_counter/Q2: U18.5, U22.5 (Q), U25.5
/sec_counter/Q3: U16.5, U18.10, U22.9 (Q), U25.10
/sec_counter/Q4: U16.9, U18.13, U24.5 (Q), U25.13
/sec_counter/Q5: U16.10, U19.2, U24.9 (Q)
/sec_counter/Q012: U18.9, U25.6, U25.9
/sec_counter/Q0123: U18.12, U25.8, U25.12
/sec_counter/Q01234: U19.1, U25.11
/sec_counter/~=59?: U15.2, U20.1, U20.4, U20.9, U20.12, U21.1
/sec_counter/~Q1: U17.8 (~Q)
/sec_counter/~Q2: U16.4, U22.6 (~Q)
/sec_counter/~Q3: U22.8 (~Q)
/sec_counter/~Q4: U24.6 (~Q)
/sec_counter/~Q5: U24.8 (~Q)
/~RESET_PULSE: U17.1 (~R), U17.13 (~R), U22.1 (~R), U22.13 (~R), U24.1 (~R), U24.13 (~R); also elsewhere on the board
GND: U16.7 (GND), U17.7 (GND), U18.7 (GND), U19.4, U19.5, U19.7 (GND), U19.9, U19.10, U19.12, U19.13, U20.7 (GND), U21.7 (GND), U21.9, U21.10, U21.12, U21.13, U22.7 (GND), U23.7 (GND), U23.11 (C), U23.12 (D), U24.7 (GND), U25.7 (GND); also elsewhere on the board
unnamed: U16.8, U21.5
unnamed: U16.11, U21.4
unnamed: U16.3, U16.12
unnamed: U16.6, U16.13
unnamed: U18.3, U20.2
unnamed: U18.6, U20.5
unnamed: U18.8, U20.10
unnamed: U18.11, U20.13
unnamed: U19.3, U21.2

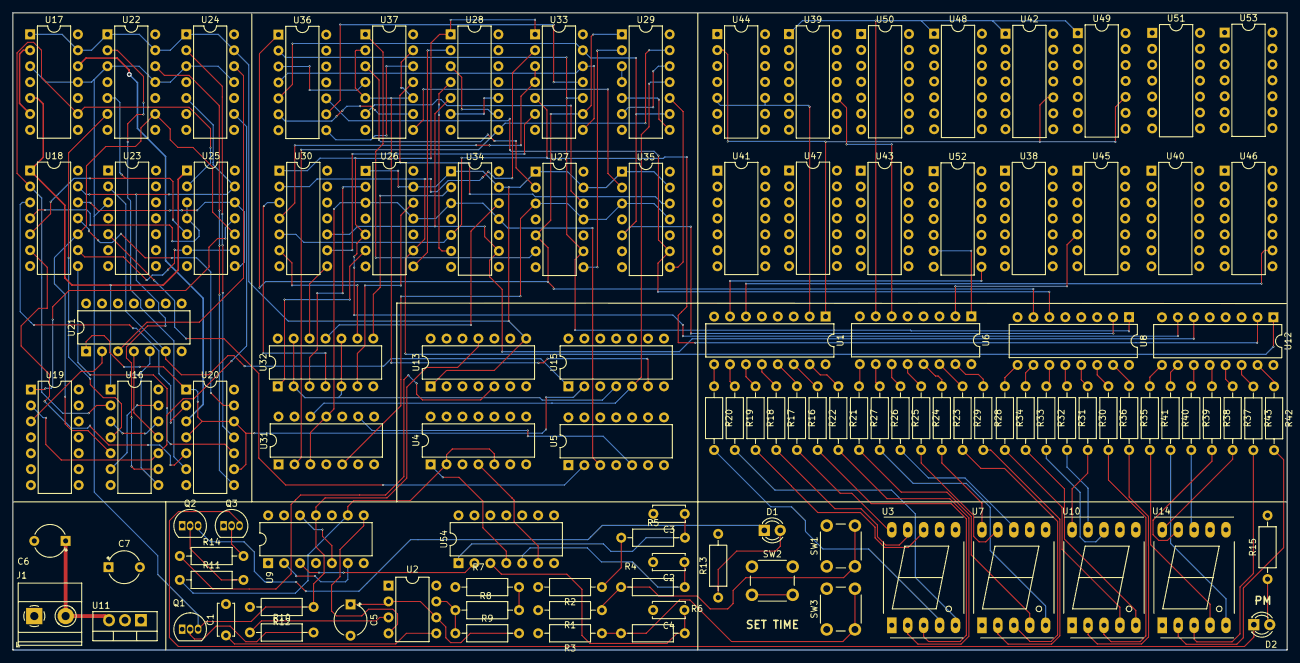
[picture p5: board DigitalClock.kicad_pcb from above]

Board: 2 copper layers, 203.2 x 101.6 mm, 113 parts (0 on the bottom side), 221 nets.

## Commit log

2023-01-02 added kicad files
    [DigitalClock.kicad_pcb, DigitalClock.kicad_sch, hour_counter.kicad_sch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]
2023-01-02 added minute counter schematic"
    [DigitalClock.kicad_sch, hour_counter.kicad_sch, min_counter.kicad_sch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]
2023-01-03 finished kicad schematic
    [DigitalClock.kicad_sch, hour_counter.kicad_sch, min_counter.kicad_sch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]
2023-01-03 about to begin layout
    [DigitalClock.kicad_pcb, DigitalClock.kicad_sch, hour_counter.kicad_sch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]
2023-01-03 more routing
    [DigitalClock.kicad_pcb, DigitalClock.kicad_sch, sec_counter.kicad_sch]
2023-01-05 more layout
    [DigitalClock.kicad_pcb, DigitalClock.kicad_sch]
2023-01-05 started routing
    [DigitalClock.kicad_pcb, DigitalClock.kicad_sch, hour_counter.kicad_sch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]
2023-01-05 finished pcb
2023-01-05 created bom and gerbers
    [DigitalClock-B_Cu.gbr, DigitalClock-B_Mask.gbr, DigitalClock-B_Paste.gbr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]
2023-01-05 small updates to board
    [DigitalClock-B_Cu.gbr, DigitalClock-B_Mask.gbr, DigitalClock-B_Paste.gbr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]
